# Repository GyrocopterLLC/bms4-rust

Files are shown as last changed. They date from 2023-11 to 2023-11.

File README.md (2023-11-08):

# bms4-rust
Firmware for a 4-cell modular lithium ion battery management system ("BMS").  
Programmed in Rust.  
## Hardware
The bms4_f051 board.  
Click [hardware](hardware) to see the board design files.  
This board uses an STM32F051K8 microcontroller, and 4 op-amps in a differential amplifier configuration to measure the voltage of 4 batteries stacked in series.

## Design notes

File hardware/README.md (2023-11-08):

# bms4_f051 Hardware Design Files
Designed in Kicad 7.0  
<https://www.kicad.org/>  

## Board Notes
Based on STM32F051K8 microcontroller.  
Uses 2x dual LM2904 op-amps to measure the voltage of the lithium ion batteries. Stepping down the voltage is necessary to avoid damaging the microcontroller's input pins which are limited to 3.3V.
Balancing is performed by 33 ohm shunt resistors, one per cell. The are turned on by the microcontroller through external FETs (AO3400A).
Communication is done through an isolation circuit (ISO7221D). This is used to be able to communicate to other bms4_f051 boards in a series battery configuration. In series, the boards will not share grounds. Connecting one board's ground to another board's ground would create a dangerous short circuit through the LiIon batteries! The boards are designed to be daisy-chained in communication, with the bottom-most (or top-most, your choice) board connected to an external controller, for example an ebike motor controller.

## Board Images
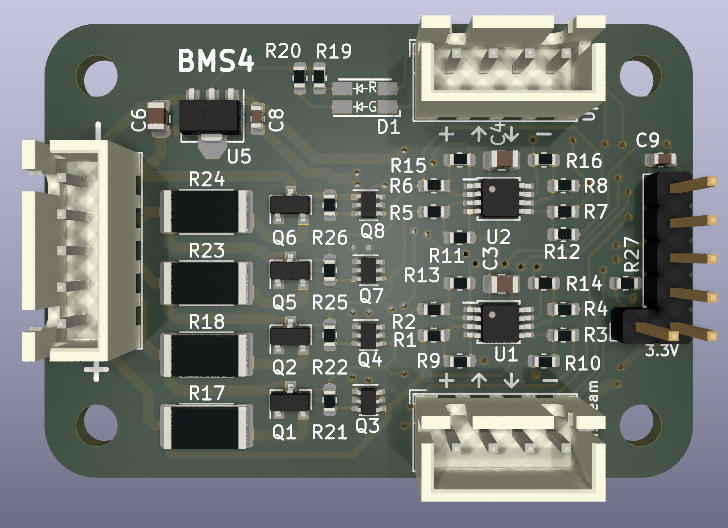
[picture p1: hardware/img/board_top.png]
Board Top

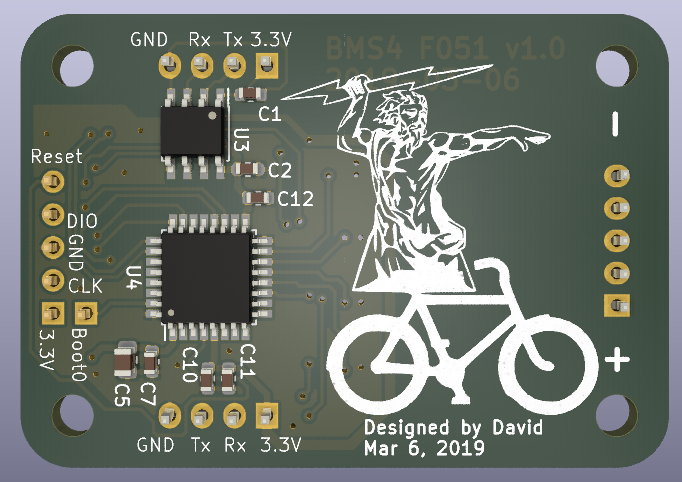
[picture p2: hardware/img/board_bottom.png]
Board Bottom

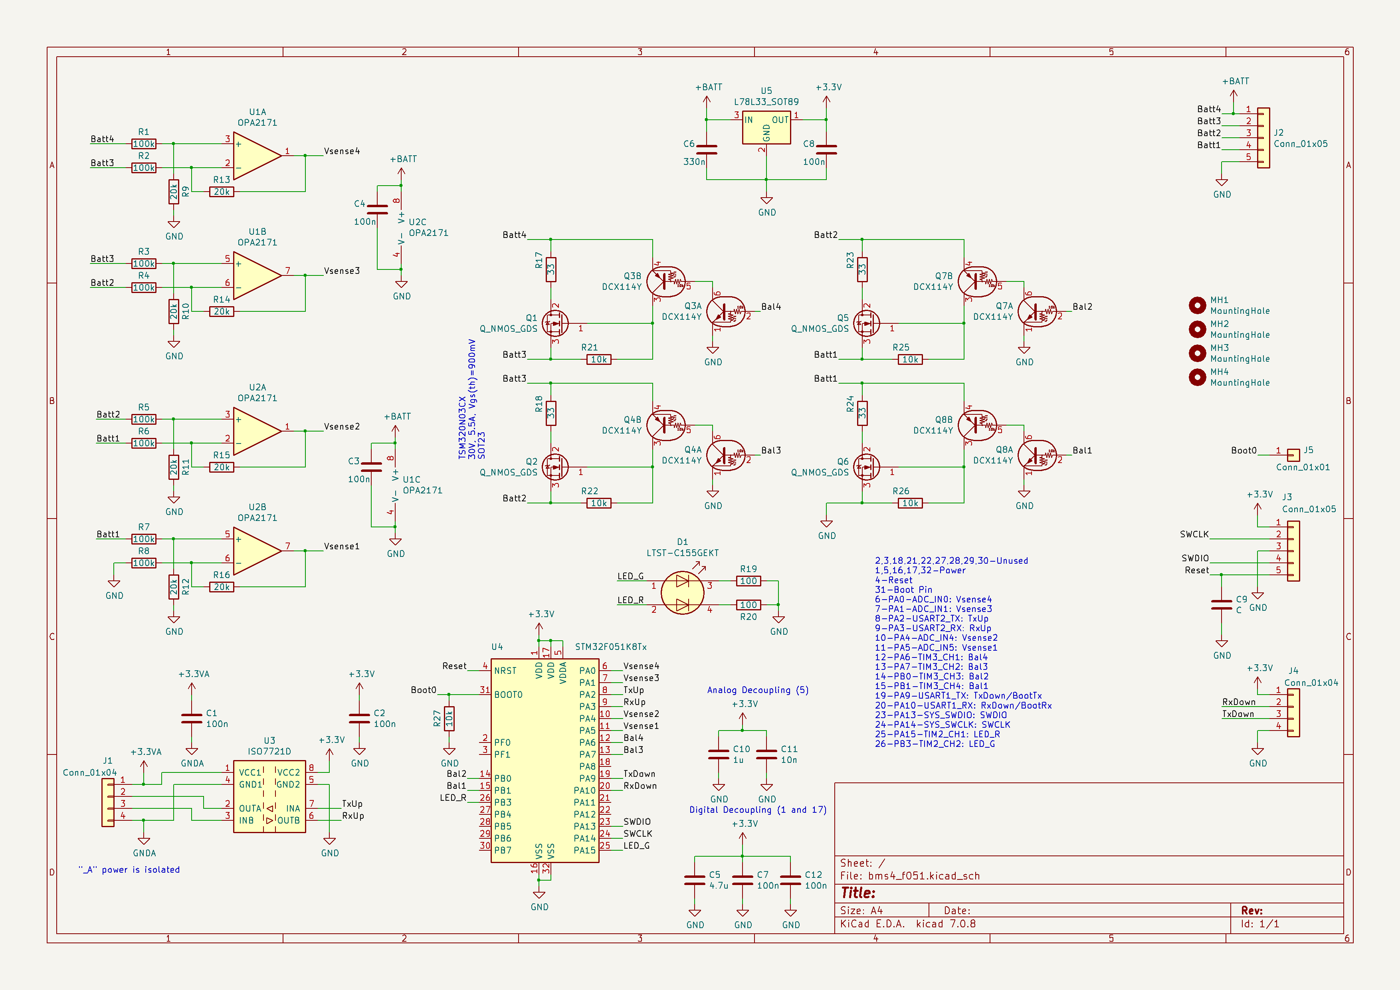
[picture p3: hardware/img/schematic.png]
Schematic


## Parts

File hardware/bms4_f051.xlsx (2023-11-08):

Source: | D:\pcb\bms4_f051\bms4_f051.sch
Date: | 2019-02-13 07:07
Tool: | Eeschema (5.0.0)
Component Count: | 61
Ref | Value | Footprint | Part Number | Manufacturer
C1 | 100n | Capacitor_SMD:C_0603_1608Metric | CL10A104KA8NNNC | Samsung Electro-Mechanics
C2 | 100n | Capacitor_SMD:C_0603_1608Metric | CL10A104KA8NNNC
C3 | 100n | Capacitor_SMD:C_0805_2012Metric
C4 | 100n | Capacitor_SMD:C_0805_2012Metric
C5 | 4.7u | Capacitor_SMD:C_0805_2012Metric
C6 | 330n | Capacitor_SMD:C_0805_2012Metric | CL21B334KBFNNNE | Samsung Electro-Mechanics
C7 | 100n | Capacitor_SMD:C_0603_1608Metric | CL10A104KA8NNNC
C8 | 100n | Capacitor_SMD:C_0603_1608Metric | CL10A104KA8NNNC
C9 | C | Capacitor_SMD:C_0603_1608Metric
C10 | 100n | Capacitor_SMD:C_0603_1608Metric
C11 | 100n | Capacitor_SMD:C_0603_1608Metric
C12 | 100n | Capacitor_SMD:C_0603_1608Metric
D1 | LTST-C155GEKT | LED_SMD:LED_Avago_PLCC4_3.2x2.8mm_CW
J1 | Conn_01x04 | Connector_JST:JST_XH_B04B-XH-A_1x04_P2.50mm_Vertical
J2 | Conn_01x05 | Connector_JST:JST_XH_B05B-XH-A_1x05_P2.50mm_Vertical
J3 | Conn_01x05 | Connector_PinHeader_2.54mm:PinHeader_1x05_P2.54mm_Vertical
J4 | Conn_01x04 | Connector_JST:JST_XH_B04B-XH-A_1x04_P2.50mm_Vertical
J5 | Conn_01x01 | Connector_PinHeader_2.54mm:PinHeader_1x01_P2.54mm_Vertical
MH1 | MountingHole | MountingHole:MountingHole_3.2mm_M3
MH2 | MountingHole | MountingHole:MountingHole_3.2mm_M3
MH3 | MountingHole | MountingHole:MountingHole_3.2mm_M3
MH4 | MountingHole | MountingHole:MountingHole_3.2mm_M3
Q1 | Q_NMOS_GDS | Package_TO_SOT_SMD:SOT-23 | AO3400A
Q2 | Q_NMOS_GDS | Package_TO_SOT_SMD:SOT-23 | AO3400A
Q3 | DCX114Y | Package_TO_SOT_SMD:SOT-363_SC-70-6 | DCX114YU-7-F | Diodes Incorporated
Q4 | DCX114Y | Package_TO_SOT_SMD:SOT-363_SC-70-6 | DCX114YU-7-F
Q5 | Q_NMOS_GDS | Package_TO_SOT_SMD:SOT-23 | AO3400A
Q6 | Q_NMOS_GDS | Package_TO_SOT_SMD:SOT-23 | AO3400A
Q7 | DCX114Y | Package_TO_SOT_SMD:SOT-363_SC-70-6 | DCX114YU-7-F
Q8 | DCX114Y | Package_TO_SOT_SMD:SOT-363_SC-70-6 | DCX114YU-7-F
R1 | 100k | Resistor_SMD:R_0603_1608Metric | ERA-3AED104V | Panasonic Electronic Components
R2 | 100k | Resistor_SMD:R_0603_1608Metric | ERA-3AED104V
R3 | 100k | Resistor_SMD:R_0603_1608Metric | ERA-3AED104V
R4 | 100k | Resistor_SMD:R_0603_1608Metric | ERA-3AED104V
R5 | 100k | Resistor_SMD:R_0603_1608Metric | ERA-3AED104V
R6 | 100k | Resistor_SMD:R_0603_1608Metric | ERA-3AED104V
R7 | 100k | Resistor_SMD:R_0603_1608Metric | ERA-3AED104V
R8 | 100k | Resistor_SMD:R_0603_1608Metric | ERA-3AED104V
R9 | 20k | Resistor_SMD:R_0603_1608Metric | ERA-3AED203V | Panasonic Electronic Components
R10 | 20k | Resistor_SMD:R_0603_1608Metric | ERA-3AED203V
R11 | 20k | Resistor_SMD:R_0603_1608Metric | ERA-3AED203V
R12 | 20k | Resistor_SMD:R_0603_1608Metric | ERA-3AED203V
R13 | 20k | Resistor_SMD:R_0603_1608Metric | ERA-3AED203V
R14 | 20k | Resistor_SMD:R_0603_1608Metric | ERA-3AED203V
R15 | 20k | Resistor_SMD:R_0603_1608Metric | ERA-3AED203V
R16 | 20k | Resistor_SMD:R_0603_1608Metric | ERA-3AED203V
R17 | 33 | Resistor_SMD:R_2512_6332Metric | CRCW251233R0JNEG | Vishay Dale
R18 | 33 | Resistor_SMD:R_2512_6332Metric | CRCW251233R0JNEG
R19 | 100 | Resistor_SMD:R_0603_1608Metric
R20 | 100 | Resistor_SMD:R_0603_1608Metric
R21 | 10k | Resistor_SMD:R_0603_1608Metric
R22 | 10k | Resistor_SMD:R_0603_1608Metric
R23 | 33 | Resistor_SMD:R_2512_6332Metric | CRCW251233R0JNEG
R24 | 33 | Resistor_SMD:R_2512_6332Metric | CRCW251233R0JNEG
R25 | 10k | Resistor_SMD:R_0603_1608Metric
R26 | 10k | Resistor_SMD:R_0603_1608Metric
R27 | 10k | Resistor_SMD:R_0603_1608Metric
U1 | OPA2171 | Package_SO:TSSOP-8_3x3mm_P0.65mm | LM2904AM8-13 | Diodes Incorporated
U2 | OPA2171 | Package_SO:TSSOP-8_3x3mm_P0.65mm | LM2904AM8-13
U3 | ISO7721D | Package_SO:SOIC-8_3.9x4.9mm_P1.27mm | ISO7721DR | Texas Instruments
U4 | STM32F051K8Tx | Package_QFP:LQFP-32_7x7mm_P0.8mm
U5 | L78L33_SOT89 | Package_TO_SOT_SMD:SOT-89-3 | L78L33ABUTR | STMicroelectronics

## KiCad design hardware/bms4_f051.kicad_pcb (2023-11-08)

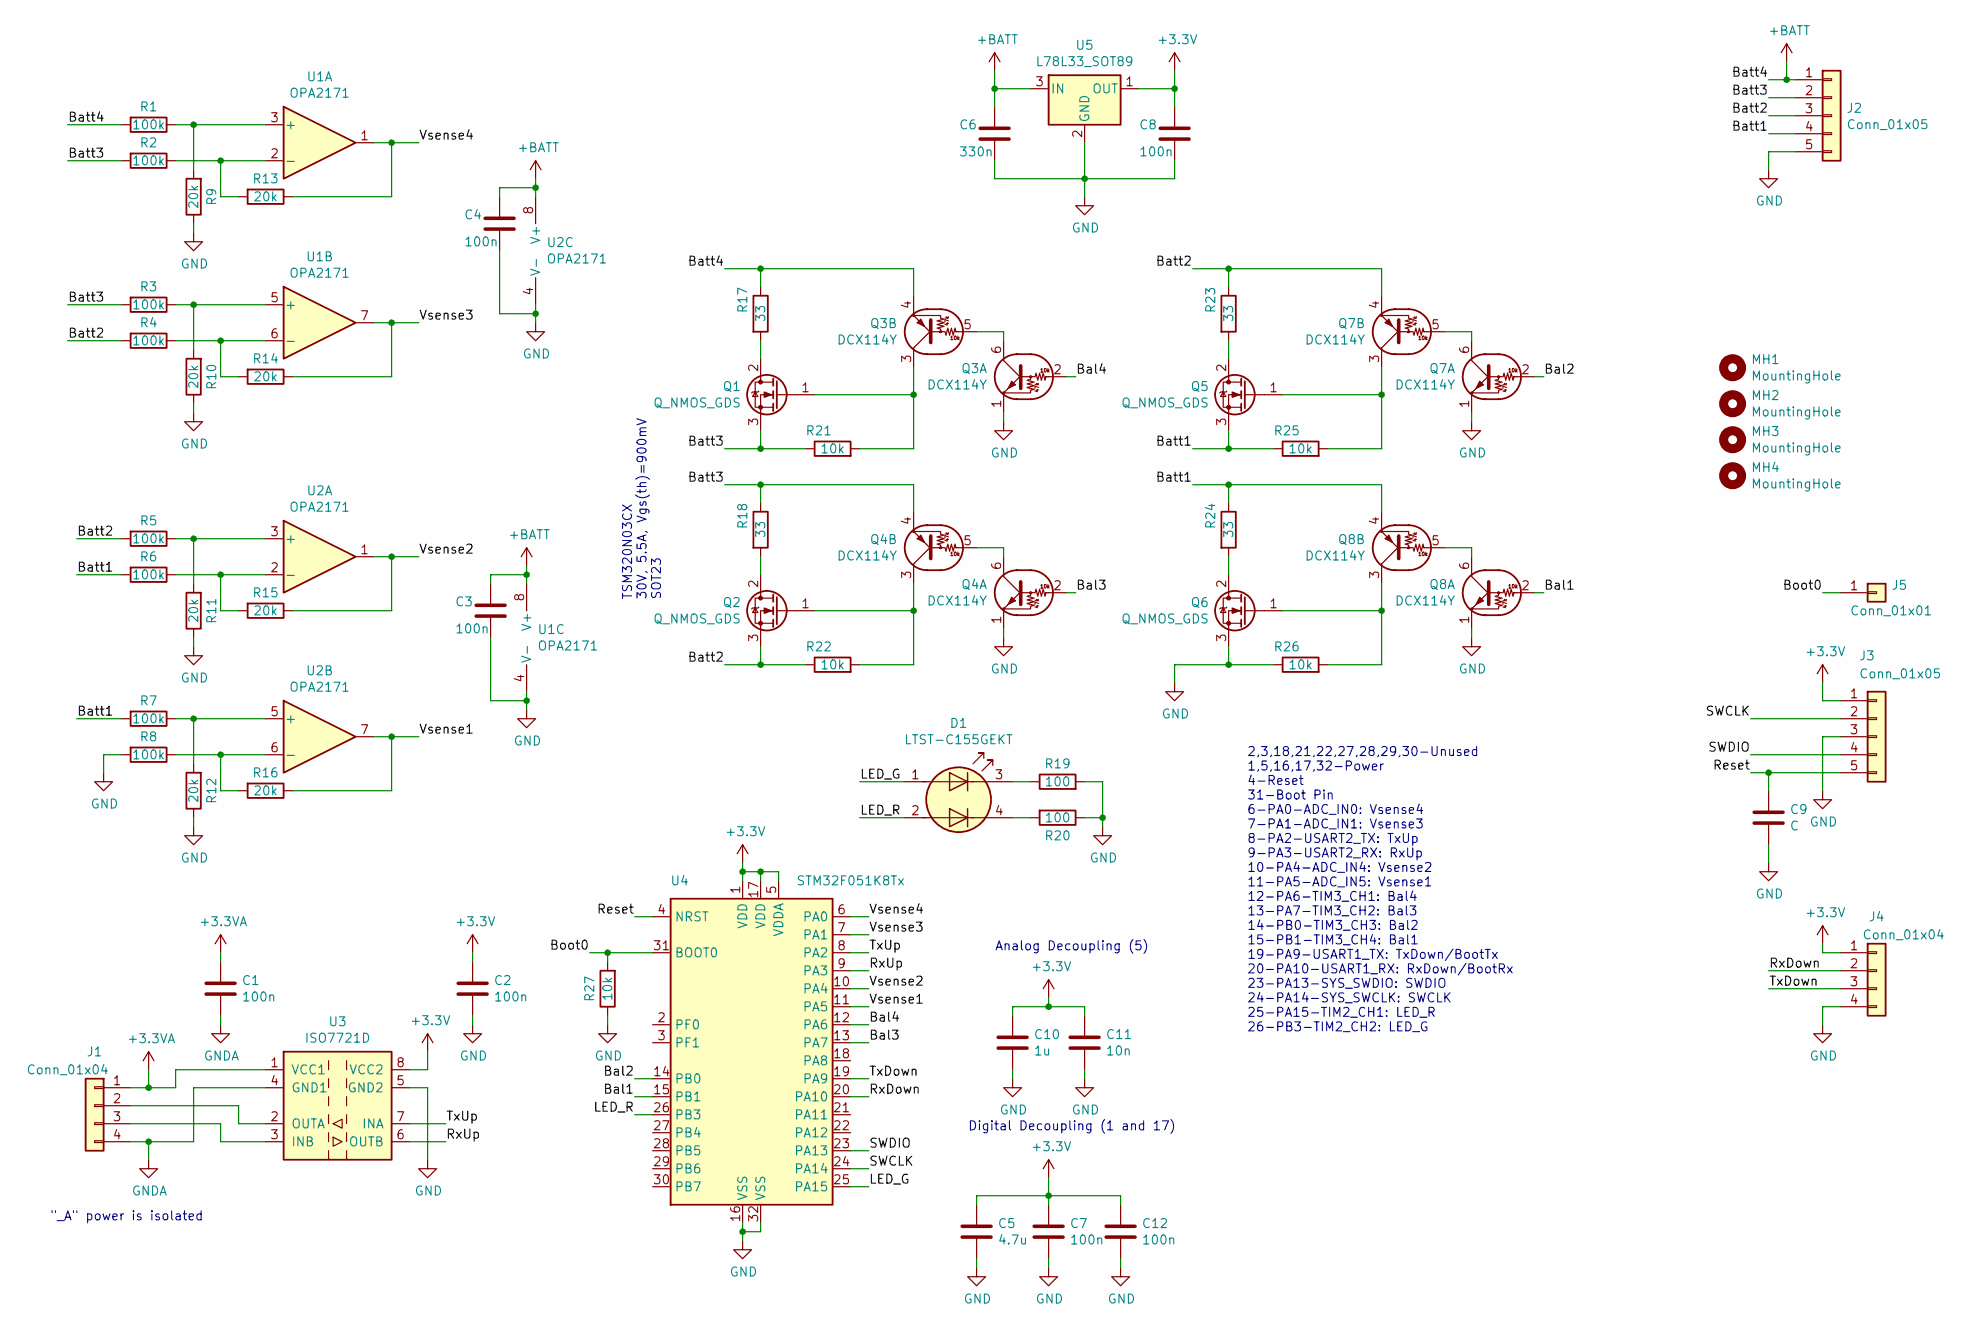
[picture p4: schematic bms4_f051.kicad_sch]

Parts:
C1, C2, C7, C8, C12: 100n; C_0603_1608Metric
C3, C4: 100n; C_0805_2012Metric
C5: 4.7u; C_0805_2012Metric
C6: 330n; C_0805_2012Metric
C9: C; C_0603_1608Metric
C10: 1u; C_0603_1608Metric
C11: 10n; C_0603_1608Metric
D1: LTST-C155GEKT
J1, J4: Conn_01x04; JST_XH_B04B-XH-A_1x04_P2.50mm_Vertical
J2: Conn_01x05; JST_XH_B05B-XH-A_1x05_P2.50mm_Vertical
J3: Conn_01x05; PinHeader_1x05_P2.54mm_Vertical
J5: Conn_01x01; PinHeader_1x01_P2.54mm_Vertical
MH1, MH2, MH3, MH4: MountingHole; MountingHole_3.2mm_M3
Q1, Q2, Q5, Q6: Q_NMOS_GDS; SOT-23
Q3, Q4, Q7, Q8: DCX114Y; SOT-363_SC-70-6
R1, R2, R3, R4, R5, R6, R7, R8: 100k; R_0603_1608Metric
R9, R10, R11, R12, R13, R14, R15, R16: 20k; R_0603_1608Metric
R17, R18, R23, R24: 33; R_2512_6332Metric
R19, R20: 100; R_0603_1608Metric
R21, R22, R25, R26, R27: 10k; R_0603_1608Metric
U1, U2: OPA2171; TSSOP-8_3x3mm_P0.65mm
U3: ISO7721D; SOIC-8_3.9x4.9mm_P1.27mm
U4: STM32F051K8Tx; LQFP-32_7x7mm_P0.8mm
U5: L78L33_SOT89; SOT-89-3

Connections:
+3.3VA: C1.1, J1.1, U3.1 (VCC1)
+3V3: C2.1, C5.1, C7.1, C8.1, C10.1, C11.1, C12.1, J3.1, J4.1, U3.8 (VCC2), U4.1 (VDD), U4.5 (VDDA), U4.17 (VDD), U5.1 (OUT)
+BATT: C3.1, C4.1, C6.1, J2.1, Q3.4 (E), R1.2, R17.1, U1.8 (V+), U2.8 (V+), U5.3 (IN)
/Bal1: Q8.2 (B), U4.15 (PB1)
/Bal2: Q7.2 (B), U4.14 (PB0)
/Bal3: Q4.2 (B), U4.13 (PA7)
/Bal4: Q3.2 (B), U4.12 (PA6)
/Batt1: J2.4, Q5.3 (S), Q8.4 (E), R6.2, R7.2, R24.1, R25.1
/Batt2: J2.3, Q2.3 (S), Q7.4 (E), R4.2, R5.2, R22.1, R23.1
/Batt3: J2.2, Q1.3 (S), Q4.4 (E), R2.2, R3.2, R18.1, R21.1
/Boot0: J5.1, R27.2, U4.31 (BOOT0)
/LED_G: D1.1 (A1), U4.25 (PA15)
/LED_R: D1.2 (A2), U4.26 (PB3)
/Reset: C9.1, J3.5, U4.4 (NRST)
/RxDown: J4.2, U4.20 (PA10)
/RxUp: U3.6 (OUTB), U4.9 (PA3)
/SWCLK: J3.2, U4.24 (PA14)
/SWDIO: J3.4, U4.23 (PA13)
/TxDown: J4.3, U4.19 (PA9)
/TxUp: U3.7 (INA), U4.8 (PA2)
/Vsense1: R16.1, U2.7, U4.11 (PA5)
/Vsense2: R15.1, U2.1, U4.10 (PA4)
/Vsense3: R14.1, U1.7, U4.7 (PA1)
/Vsense4: R13.1, U1.1, U4.6 (PA0)
GND: C2.2, C3.2, C4.2, C5.2, C6.2, C7.2, C8.2, C9.2, C10.2, C11.2, C12.2, J2.5, J3.3, J4.4, Q3.1 (E), Q4.1 (E), Q6.3 (S), Q7.1 (E), Q8.1 (E), R8.2, R9.1, R10.1, R11.1, R12.1, R19.2, R20.1, R26.1, R27.1, U1.4 (V-), U2.4 (V-), U3.5 (GND2), U4.16 (VSS), U4.32 (VSS), U5.2 (GND)
GNDA: C1.2, J1.4, U3.4 (GND1)
unnamed: D1.3 (K1), R19.1
unnamed: D1.4 (K2), R20.2
unnamed: J1.2, U3.2 (OUTA)
unnamed: J1.3, U3.3 (INB)
unnamed: Q1.1 (G), Q3.3 (C), R21.2
unnamed: Q1.2 (D), R17.2
unnamed: Q2.1 (G), Q4.3 (C), R22.2
unnamed: Q2.2 (D), R18.2
unnamed: Q3.5 (B), Q3.6 (C)
unnamed: Q4.5 (B), Q4.6 (C)
unnamed: Q5.1 (G), Q7.3 (C), R25.2
unnamed: Q5.2 (D), R23.2
unnamed: Q6.1 (G), Q8.3 (C), R26.2
unnamed: Q6.2 (D), R24.2
unnamed: Q7.5 (B), Q7.6 (C)
unnamed: Q8.5 (B), Q8.6 (C)
unnamed: R1.1, R9.2, U1.3 (+)
unnamed: R3.1, R10.2, U1.5 (+)
unnamed: R5.1, R11.2, U2.3 (+)
unnamed: R7.1, R12.2, U2.5 (+)
unnamed: R2.1, R13.2, U1.2 (-)
unnamed: R4.1, R14.2, U1.6 (-)
unnamed: R6.1, R15.2, U2.2 (-)
unnamed: R8.1, R16.2, U2.6 (-)

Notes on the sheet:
Digital Decoupling (1 and 17)
2,3,18,21,22,27,28,29,30-Unused 1,5,16,17,32-Power 4-Reset 31-Boot Pin 6-PA0-ADC_IN0: Vsense4 7-PA1-ADC_IN1: Vsense3 8-PA2-USART2_TX: TxUp 9-PA3-USART2_RX: RxUp 10-PA4-ADC_IN4: Vsense2 11-PA5-ADC_IN5: Vsense1 12-PA6-TIM3_CH1: Bal4 13-PA7-TIM3_CH2: Bal3 14-PB0-TIM3_CH3: Bal2 15-PB1-TIM3_CH4: Bal1 19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
Analog Decoupling (5)
"_A" power is isolated
TSM320N03CX 30V, 5.5A, Vgs(th)=900mV SOT23

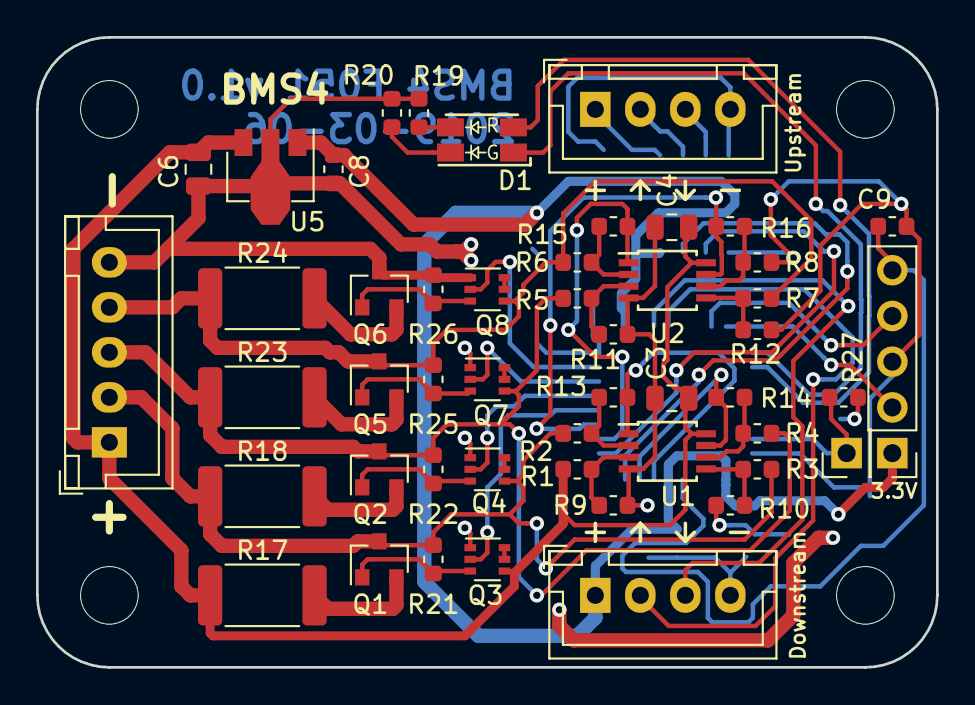
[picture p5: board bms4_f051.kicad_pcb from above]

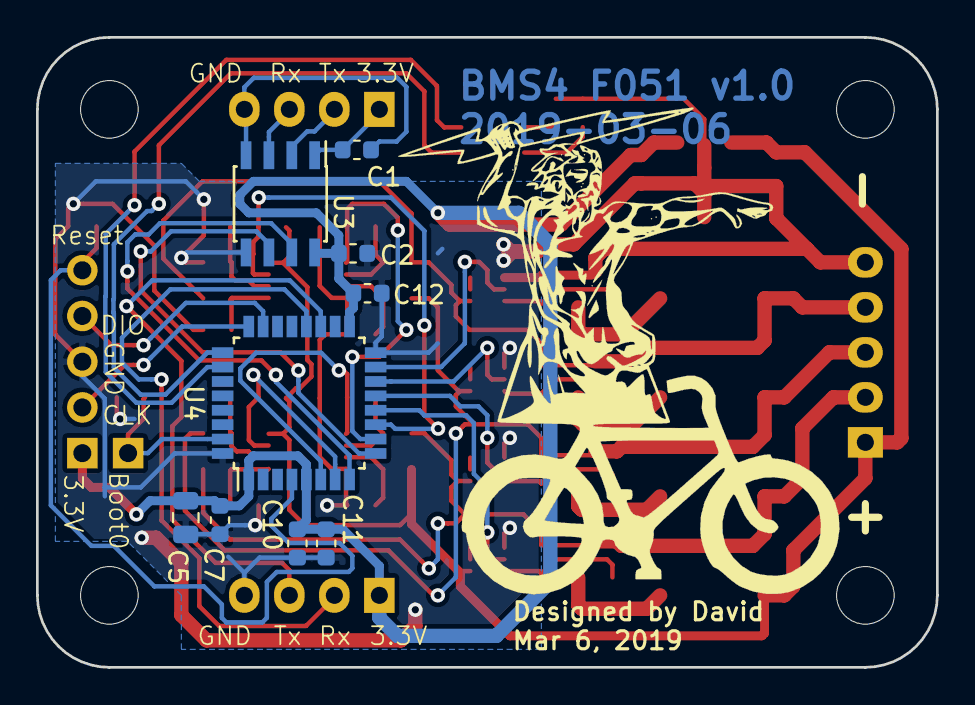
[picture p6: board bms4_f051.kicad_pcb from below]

Board: 2 copper layers, 50.0 x 35.0 mm, 62 parts (9 on the bottom side), 50 nets.

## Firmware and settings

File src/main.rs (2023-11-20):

// Blinky example from STM32F0xx-HAL

// This is simply a stub for now. The real work is yet to be done. 
// The toolchain (VScode + rust + GDB + openocd) is tested and works.

#![no_main]
#![no_std]

use adc_helper::HelpfulAdc;
use hal::pac::Interrupt;
use hal::pac::interrupt;
use hal::pac::adc::smpr::SMP_A;
use panic_halt as _;

use stm32f0xx_hal as hal;

use crate::hal::{gpio::*, pac, adc::*, prelude::*};

use cortex_m::{interrupt::Mutex, peripheral::syst::SystClkSource::Core, Peripherals};
use cortex_m_rt::{entry, exception};

use core::cell::RefCell;
use core::cell::UnsafeCell;
use core::ops::{DerefMut, Deref};

mod adc_helper;

struct LEDS{
    green: gpioa::PA15<Output<PushPull>>,
    red: gpiob::PB3<Output<PushPull>>
}

struct AdcPins {
    bat1: gpioa::PA5<Analog>,
    bat2: gpioa::PA4<Analog>,
    bat3: gpioa::PA1<Analog>,
    bat4: gpioa::PA0<Analog>
}

struct ForceSync<T> {
    inner: UnsafeCell<T>,
}

impl<T> ForceSync<T> {
    /// Creates a new sync forcer
    const fn new(value: T) -> Self {
        ForceSync {
            inner: UnsafeCell::new(value),
        }
    }

    fn borrow(& self) -> & T {
        unsafe { &*self.inner.get() }
    }
}

unsafe impl<T> Sync for ForceSync<T> where T: Send {}


const ADC_FLAG:u32 = 1;
const ADC_COMPLETE_FLAG:u32 = 2;

static GPIO_LEDS: Mutex<RefCell<Option<LEDS>>> = Mutex::new(RefCell::new(None));
static GPIO_ADCS: Mutex<RefCell<Option<AdcPins>>> = Mutex::new(RefCell::new(None));
static MAIN_LOOP_FLAGS: Mutex<RefCell<u32>> = Mutex::new(RefCell::new(0));
static ADC_RESULTS: Mutex<RefCell<[u16;4]>> = Mutex::new(RefCell::new([0;4]));
//#[link_section=".data"]
//static ADC_RESULTS: [u16;4] = [0;4];
//static ADC_RESULTS: ForceSync<RefCell<[u16;4]>> = ForceSync::new(RefCell::new([0;4]));
static DMA_PERIPH: Mutex<RefCell<Option<pac::DMA1>>> = Mutex::new(RefCell::new(None));
// static ADC_PERIPH: Mutex<RefCell<Option<Adc>>> = Mutex::new(RefCell::new(None));
static ADC_PERIPH: Mutex<RefCell<Option<HelpfulAdc>>> = Mutex::new(RefCell::new(None));
#[entry]
fn main() -> ! {
    //let mut adc_results = [0_u16;4];


    if let (Some(mut p), Some(cp)) = (pac::Peripherals::take(), Peripherals::take()) {
        cortex_m::interrupt::free(move |cs| {
            
            let mut rcc = p.RCC.configure().sysclk(48.mhz()).freeze(&mut p.FLASH);

            let gpioa = p.GPIOA.split(&mut rcc);
            let gpiob = p.GPIOB.split(&mut rcc);

            // (Re-)configure PA15 and PB3 as output
            let mut ledg = gpioa.pa15.into_push_pull_output(cs);
            let mut ledr = gpiob.pb3.into_push_pull_output(cs);

            // Ensure the LEDs are off
            ledg.set_low().ok();
            ledr.set_low().ok();

            // Configure ADC inputs: PA5, 4, 1, and 0 (In1, 2, 3, and 4 respectively)
            let mut in1 = gpioa.pa5.into_analog(cs);
            let mut in2 = gpioa.pa4.into_analog(cs);
            let mut in3 = gpioa.pa1.into_analog(cs);
            let mut in4 = gpioa.pa0.into_analog(cs);
            
            // let mut madc = Adc::new(p.ADC, &mut rcc);
            //let mut madc = HelpfulAdc::new(p.ADC, &mut rcc.regs);
            // Annoyingly, using the HAL causes us to lose access to the underlying RCC registers
            // And the features we need (like enabling HSI14, enabling DMA clock) are not available
            // through the HAL. 
            // So we resort to thievery.
            let mut stolen_p: pac::Peripherals;
            unsafe{ stolen_p = pac::Peripherals::steal(); }

            let mut madc = HelpfulAdc::new(p.ADC, &mut stolen_p.RCC); 
            let dest:u32 = ADC_RESULTS.borrow(cs).as_ptr() as u32;
            madc.dma_en(&mut p.DMA1, &mut p.SYSCFG, &mut stolen_p.RCC, dest);
            //madc.dma_en(&mut p.DMA1, &mut p.SYSCFG, &mut stolen_p.RCC, &ADC_RESULTS);

            madc.set_sample_time(SMP_A::CYCLES13_5);
            madc.set_pin(&mut in1);
            madc.set_pin(&mut in2);
            madc.set_pin(&mut in3);
            madc.set_pin(&mut in4);
            *DMA_PERIPH.borrow(cs).borrow_mut() = Some(p.DMA1);
            *ADC_PERIPH.borrow(cs).borrow_mut() = Some(madc);

            // Transfer GPIO into a shared structure
            *GPIO_LEDS.borrow(cs).borrow_mut() = Some(LEDS{green:ledg, red:ledr});
            *GPIO_ADCS.borrow(cs).borrow_mut() = Some(AdcPins{bat1:in1, bat2:in2, bat3: in3, bat4: in4});

            let mut syst = cp.SYST;

            // Initialise SysTick counter with a defined value
            unsafe { syst.cvr.write(1) };

            // Set source for SysTick counter, here full operating frequency (== 48MHz)
            syst.set_clock_source(Core);

            // Set reload value, i.e. timer delay 48 MHz/4 Mcounts == 12Hz or 83ms
            syst.set_reload(4_000_000 - 1);

            // Start counting
            syst.enable_counter();

            // Enable interrupt generation
            syst.enable_interrupt();
        });
    }

    loop {
        // Superloop controls the different functions
        // Timer used to initiate functions

        let run_adc: bool = cortex_m::interrupt::free(|cs| -> bool {
            let flags = *MAIN_LOOP_FLAGS.borrow(cs).borrow();
            (flags & ADC_FLAG) != 0
            //flags & ADC_FLAG != 0 // return value is true if the ADC_FLAG bit is set
        });

        let adc_complete: bool = cortex_m::interrupt::free(|cs| -> bool {
            let flags = *MAIN_LOOP_FLAGS.borrow(cs).borrow();
            (flags & ADC_COMPLETE_FLAG) != 0
            //flags & ADC_FLAG != 0 // return value is true if the ADC_FLAG bit is set
        });

        if run_adc {
                      
            cortex_m::interrupt::free(|cs| {
                let mut flags = *MAIN_LOOP_FLAGS.borrow(cs).borrow();
                flags = flags & (!ADC_FLAG);
                *MAIN_LOOP_FLAGS.borrow(cs).borrow_mut() = flags;

                if let (Some(adc_periph), Some(dma_periph)) = 
                    (ADC_PERIPH.borrow(cs).borrow_mut().deref_mut(), DMA_PERIPH.borrow(cs).borrow_mut().deref_mut()) {
                        adc_periph.dma_start(dma_periph);
                }

                /*
                if let (Some(adc_channels), Some(adc_periph)) = 
                    (GPIO_ADCS.borrow(cs).borrow_mut().deref_mut(), ADC_PERIPH.borrow(cs).borrow_mut().deref_mut())
                {
                    let mut adc_results:[u32;4] = [0;4];
                    for i in 0..4 {
                        adc_results[i] = match i {
                            0 => adc_periph.read(&mut adc_channels.bat1).ok().unwrap_or_default(),
                            1 => adc_periph.read(&mut adc_channels.bat2).ok().unwrap_or_default(),
                            2 => adc_periph.read(&mut adc_channels.bat3).ok().unwrap_or_default(),
                            _ => adc_periph.read(&mut adc_channels.bat4).ok().unwrap_or_default()
                        };
                    }

                    *ADC_RESULTS.borrow(cs).borrow_mut() = adc_results;

                }; */

            });
        }

        if adc_complete {
            // check our values
            //if(ADC_RESULTS[0] < ADC_RESULTS[3]) {
                // put on a light show
            cortex_m::interrupt::free(|cs| {
                let adc_conversions = *ADC_RESULTS.borrow(cs).borrow();
                if adc_conversions[0] < adc_conversions[3] {

                    if let Some(ref mut led) = GPIO_LEDS.borrow(cs).borrow_mut().deref_mut() {
                        led.red.set_high().ok();
                    }
                }
            });
            //}
        }
    }
}

// Define an exception handler, i.e. function to call when exception occurs. Here, if our SysTick
// timer generates an exception the following handler will be called
#[exception]
fn SysTick() {
    // Exception handler state variable
    static mut STATE: u8 = 1;

    // Enter critical section
    cortex_m::interrupt::free(|cs| {
        // Borrow access to our GPIO pin from the shared structure
        if let Some(ref mut led) = GPIO_LEDS.borrow(cs).borrow_mut().deref_mut() {
            // Check state variable, keep LED off most of the time and turn it on every 10th tick
            if *STATE < 10 {
                // Turn off the LED
                led.green.set_low().ok();
                //led.red.set_high().ok();

                // And now increment state variable
                *STATE += 1;
            } else {
                // Turn on the LED
                led.green.set_high().ok();
                //led.red.set_low().ok();

                // And set new state variable back to 0
                *STATE = 0;

                let mut flags = *MAIN_LOOP_FLAGS.borrow(cs).borrow().deref();
                flags = flags | ADC_FLAG;
                *MAIN_LOOP_FLAGS.borrow(cs).borrow_mut() = flags;
            }
        }
    });
}


#[interrupt]
fn DMA1_CH1() {
    cortex_m::interrupt::free(|cs| {
        if let Some(dma) = DMA_PERIPH.borrow(cs).borrow_mut().deref_mut() {
            dma.ifcr.write(|w| {w.ctcif1().clear()});
            dma.ch1.cr.modify(|_,w|{w.en().disabled()}); // does not automatically disable the channel when transfer is complete !?
            if let Some(adc) = ADC_PERIPH.borrow(cs).borrow_mut().deref_mut() {
                adc.shutdown();
            }

            let mut flags = *MAIN_LOOP_FLAGS.borrow(cs).borrow().deref();
            flags = flags | ADC_COMPLETE_FLAG;
            *MAIN_LOOP_FLAGS.borrow(cs).borrow_mut() = flags;
        };
    });
}

#[interrupt]
fn DMA1_CH2_3_DMA2_CH1_2() {
    cortex_m::interrupt::free(|cs| {
        if let Some(dma) = DMA_PERIPH.borrow(cs).borrow_mut().deref_mut() {
            dma.ifcr.write(|w| {w.ctcif2().clear()});
            dma.ch2.cr.modify(|_,w|{w.en().disabled()});
            if let Some(adc) = ADC_PERIPH.borrow(cs).borrow_mut().deref_mut() {
                adc.shutdown();
            }

            let mut flags = *MAIN_LOOP_FLAGS.borrow(cs).borrow().deref();
            flags = flags | ADC_COMPLETE_FLAG;
            *MAIN_LOOP_FLAGS.borrow(cs).borrow_mut() = flags;
        };
    });
}

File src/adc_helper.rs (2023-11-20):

const VREFCAL: *const u16 = 0x1FFF_F7BA as *const u16;
const VTEMPCAL30: *const u16 = 0x1FFF_F7B8 as *const u16;
const VTEMPCAL110: *const u16 = 0x1FFF_F7C2 as *const u16;
const VDD_CALIB: u16 = 3300;

use crate::{gpioa, gpiob, gpioc, Analog};

use crate::pac::{
    adc::{
        cfgr1::{ALIGN_A, RES_A},
        smpr::SMP_A
    },
    RCC,
    rcc::{
        apb2enr,
        cr2
    },
    ADC,
    DMA1,
    dma1::ch::cr::{PSIZE_A, MSIZE_A},
    SYSCFG, 
    NVIC,
    Interrupt
};

pub trait Channel {
    type ID; // ex: u8
    fn channel() -> Self::ID;
}

// Convert pins to ADC channels by implementing the Channel trait
macro_rules! adc_pins {
    ($($pin:ty => $chan:expr),+ $(,)*) => {
        $(
            impl Channel for $pin {
                type ID = u8;

                fn channel() -> u8 { $chan }
            }
        )+
    };
}

adc_pins!(
    gpioa::PA0<Analog> => 0_u8,
    gpioa::PA1<Analog> => 1_u8,
    gpioa::PA2<Analog> => 2_u8,
    gpioa::PA3<Analog> => 3_u8,
    gpioa::PA4<Analog> => 4_u8,
    gpioa::PA5<Analog> => 5_u8,
    gpioa::PA6<Analog> => 6_u8,
    gpioa::PA7<Analog> => 7_u8,
    gpiob::PB0<Analog> => 8_u8,
    gpiob::PB1<Analog> => 9_u8,
    gpioc::PC0<Analog> => 10_u8,
    gpioc::PC1<Analog> => 11_u8,
    gpioc::PC2<Analog> => 12_u8,
    gpioc::PC3<Analog> => 13_u8,
    gpioc::PC4<Analog> => 14_u8,
    gpioc::PC5<Analog> => 15_u8
);

#[derive(Debug, Default)]
/// Internal temperature sensor (ADC Channel 16)
pub struct VTemp;

#[derive(Debug, Default)]
/// Internal voltage reference (ADC Channel 17)
pub struct VRef;

#[derive(Debug, Default)]
/// Battery reference voltage (ADC Channel 18)
pub struct VBat;

adc_pins!(
    VTemp => 16_u8,
    VRef  => 17_u8,
    VBat  => 18_u8
);

fn sum_of_bits(inp: u32) -> u32 {
    let mut sum = 0_u32;
    for i in 0..31 {
        if (inp & (1 << i)) != 0 {
            sum+=1;
        }
    }
    sum
}

pub struct HelpfulAdc {
    rb: ADC,
    sample_time: SMP_A,
    align: ALIGN_A,
    precision: RES_A,
    dma_mode: bool, 
    use_channel2: bool,
    channels_converted: u32
}

impl HelpfulAdc{

    pub fn new(madc: ADC, mrcc: &mut RCC) -> HelpfulAdc {
        let s: HelpfulAdc = Self { rb: madc, 
            sample_time: SMP_A::CYCLES239_5, 
            align: ALIGN_A::RIGHT, 
            precision: RES_A::TWELVEBIT,
            dma_mode: false,
            use_channel2: false,
            channels_converted: 0 };
        // Startup clocks - enable clock to ADC
        // and the HSI14 oscillator
        mrcc.apb2enr.modify(|_, w| {
            w.adcen().set_bit()
        });
        mrcc.cr2.modify(|_,w| {
            w.hsi14on().set_bit()
        });
        while mrcc.cr2.read().hsi14rdy().is_not_ready() {}

        if s.rb.cr.read().aden().is_enabled() {
            /* Clear ADEN by setting ADDIS */
            s.rb.cr.modify(|_, w| w.addis().disable());
        }
        while s.rb.cr.read().aden().is_enabled() {}

        /* Clear DMAEN */
        s.rb.cfgr1.modify(|_, w| w.dmaen().disabled());

        /* Start calibration by setting ADCAL */
        s.rb.cr.modify(|_, w| w.adcal().start_calibration());

        /* Wait until calibration is finished and ADCAL = 0 */
        while s.rb.cr.read().adcal().is_calibrating() {}

        //madc.ccr.
        s
    }

    pub fn set_sample_time(&mut self, sample_time: SMP_A) {
        self.sample_time = sample_time;
        self.rb.smpr.write(|w| {w.smp().variant(sample_time)});
    }

    pub fn set_channels(&mut self, channels_converted: u32) {
        self.channels_converted = channels_converted;
        self.rb.chselr.write(|w| {unsafe{w.bits(channels_converted)}});
    }

    pub fn set_pin<PIN:Channel<ID=u8>>(&mut self, _pin_converted: &mut PIN) {
        self.channels_converted += 1 << PIN::channel();
        self.rb.chselr.write(|w| {unsafe{w.bits(self.channels_converted)}});
    }

    //pub fn dma_en(&mut self, mdma: &mut DMA1, msyscfg: &mut SYSCFG, mrcc: &mut RCC, dest: & [u16]) -> () {
    pub fn dma_en(&mut self, mdma: &mut DMA1, msyscfg: &mut SYSCFG, mrcc: &mut RCC, dest_addr: u32) -> () {

        self.dma_mode = true;

        self.rb.cfgr1.modify(|_,w|{
            w.dmaen().enabled()
            .dmacfg().one_shot()
        });

        mrcc.ahbenr.modify(|_,w|{w.dmaen().enabled()});

        // confirm which channel in syscfg is assigned to the ADC
        self.use_channel2 = msyscfg.cfgr1.read().adc_dma_rmp().is_remapped();

        mdma.ifcr.write(|w| {
            w.ctcif1().clear()
            .ctcif2().clear()
        });

        let dmachannel = if self.use_channel2 {&mdma.ch2} else {&mdma.ch1};
        
        dmachannel.cr.write(|w| {
            w.psize().variant(PSIZE_A::BITS16)
            .msize().variant(MSIZE_A::BITS16)
            .dir().from_peripheral()
            .minc().enabled()
            .tcie().enabled()
        });

        dmachannel.mar.write(|w| {
            unsafe{w.bits(dest_addr)}
        });

        dmachannel.par.write(|w| {
            unsafe{w.bits(self.rb.dr.as_ptr() as u32)}
        });

        //dmachannel.ndtr.write(|w| {w.ndt().bits(dest.len() as u16)});

        
        
    }

    pub fn dma_start(&self, mdma: &mut DMA1) {
        // Enable DMA interrupt in NVIC
        let irq: Interrupt = if self.use_channel2 {Interrupt::DMA1_CH2_3_DMA2_CH1_2} else {Interrupt::DMA1_CH1};

        unsafe {NVIC::unmask(irq);}

        let num_conversions = sum_of_bits(self.channels_converted);

        let dmachannel = if self.use_channel2 {&mdma.ch2} else {&mdma.ch1};

        dmachannel.ndtr.write(|w| {w.ndt().bits(num_conversions as u16)});
        dmachannel.cr.modify(|_,w|{w.en().enabled()});

        if self.rb.isr.read().adrdy().is_ready() {
            self.rb.isr.modify(|_, w| w.adrdy().clear());
        }
        self.rb.cr.modify(|_, w| w.aden().enabled());
        while self.rb.isr.read().adrdy().is_not_ready() {}

        self.rb.cr.modify(|_,w|{w.adstart().start_conversion()});
    }

    pub fn shutdown(&self) {
        self.rb.cr.modify(|_, w| w.adstp().stop_conversion());
        while self.rb.cr.read().adstp().is_stopping() {}
        self.rb.cr.modify(|_, w| w.addis().disable());
        while self.rb.cr.read().aden().is_enabled() {}
    }

}

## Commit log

2023-11-08 Initial hardware and software - software is just a stub
    [bms4_f051-B.Cu.gbl, bms4_f051-B.Mask.gbs, bms4_f051-B.SilkS.gbo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]
2023-11-13 ADC tested working in blocking mode
2023-11-20 continued working on adc
